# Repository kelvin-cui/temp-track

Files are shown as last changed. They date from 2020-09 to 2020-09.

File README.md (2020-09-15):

# temp-track
Temp-track is a IOT temperature sensor designed for use in the transition back to office during the pandemic. Created as a summer stretch project for Cisco, Temp-track allows for custom API integrations with its Wifi capabilities, and features the work of Tyler Patel, Tara Rafi, Olivia Xia, Michael Fitzgerald and Kelvin Cui.

covid-19

## Background info
With the advent of the Coronavirus, the entire world shifted to working from home, in an effort to limit the possibilities of infection. COVID-19 is highly contagious, and the current best way to prevent infection is through screening. An obvious symptom of COVID-19 is a fever, with a raised internal temperature. Temperature-based screening is the most common solution right now to quickly screen people before they are allowed entry, often seen at storefronts and airports. Since COVID-19 is easily transmitted through bodily fluids, the FDA recommends "telethermographic temperature sensors", or temperature sensors that can assess skin temperature remotely. 

### Existing Solutions
There are two popular solutions that currently exist for this purpose : simple IR sensor-based forehead thermometers, and advanced IR camera-based screening stations.

covid
The point-and-shoot forehead thermometers are simple to use, but they can be very inaccurate, often featuring a variance of 0.5 degrees celsius. They're also standalone units, and allows for zero integration.

covid
The camera-based screening stations meanwhile are quite advanced, featuring a variance of 0.3 degrees celsius, and allow for integrations. However, they are very expensive, are difficult to operate, and take up a lot of space.

## Proposed Solution
We believe that our solution features the best of both currently popular solutions. It features the ease of use of the forehead thermometers, while maintaining the accuracy of the IR cameras with its medical grade IR Sensor. It also features an ESP-01 Chip, allowing for custom API integrations, and best of all, costs the same on average as the forehead thermometers.

## How it works
covid

## Hardware
The hardware is based on an Arduino Nano, as well as an ESP-01 Wifi Chip. The temperature is recorded using the Medical Grade MLX90614 IR Sensor, allowing for 0.2 degrees celsius variance. When the button is pressed, the temperature is recorded, and then sent over Wifi to a server of your choice. If the temperature is below 38 degrees celsius, then a green light flashes, indicating a pass for the screening. Conversely, if the temperature is above 38, then a red light flashes. Our current example is set up to send the temperature info to our Node Red Server through a GET call, which brings us into...

## Software
In our example, our Node Red server is set up to take the temperature info, and using the Webex Teams API, send that temperature as a message to a user through Teams.

## Our Vision
Our vision is to create an all-in-one screening and contact tracing solution, utilizing two key APIs: DNASpaces and Webex Teams. With DNASpaces, we're able to anonymously track the location of any user connected to a Cisco router in a building, and determine which people have come into contact with each other. With Webex Teams, we're also able to update the building manager of any alerts, send helpful resources to anyone who's registered a high temperature, and even allow people to self-report if they've tested positive.

### Example Workflow
An example workflow for any office with Cisco routers could be the following. An employee would scan their ID badge, and get their temperatures taken. If their temperature is abnormally high, they are prevented from entering the building. The building management gets an alert that one of their employees have registered a high temperature, and that employee would be sent helpful resources, and recommended to get tested, both through Webex Teams. If the test returns positive, the employee may self-report through Teams. If they self-report, the employee's stored location data from DNASpaces is automatically compared, and any other employee who they've come into contact with will get a notification through Teams, alerting them that someone they've come into contact with has tested positive.

## Lessons Learned
This was a very educational project, and there are a few things that we'd do differently in the future. In terms of hardware, instead of using an Arduino Nano and ESP-01, an ESP-32 is a single board that accomplishes the same thing, with less cost. Using the ESP-32 would also allow us to power the device using a Li-Po, making the device standalone instead of having to be powered over USB. The ESP-32 also has a deep-sleep mode, so that it would only draw power when the button is clicked, allowing long battery life. Furthermore, some ESP-32s feature a built-in OLED screen, which would allow for a display of the actual temperature. In terms of the server, instead of sending API calls directly to Node Red, we'd set up a MQTT server that would act as a bridge between the two to allow for more efficient communications.

## File Guide
The CAD files for the housing are featured in the CAD folder. Both a .stl and .sldprt version exists, either for direct 3D printing or modification through solidworks respectively.
The Arduino and ESP Files are found in the Code folder, and a wiring Schematic.png is present to show how everything is wired together.

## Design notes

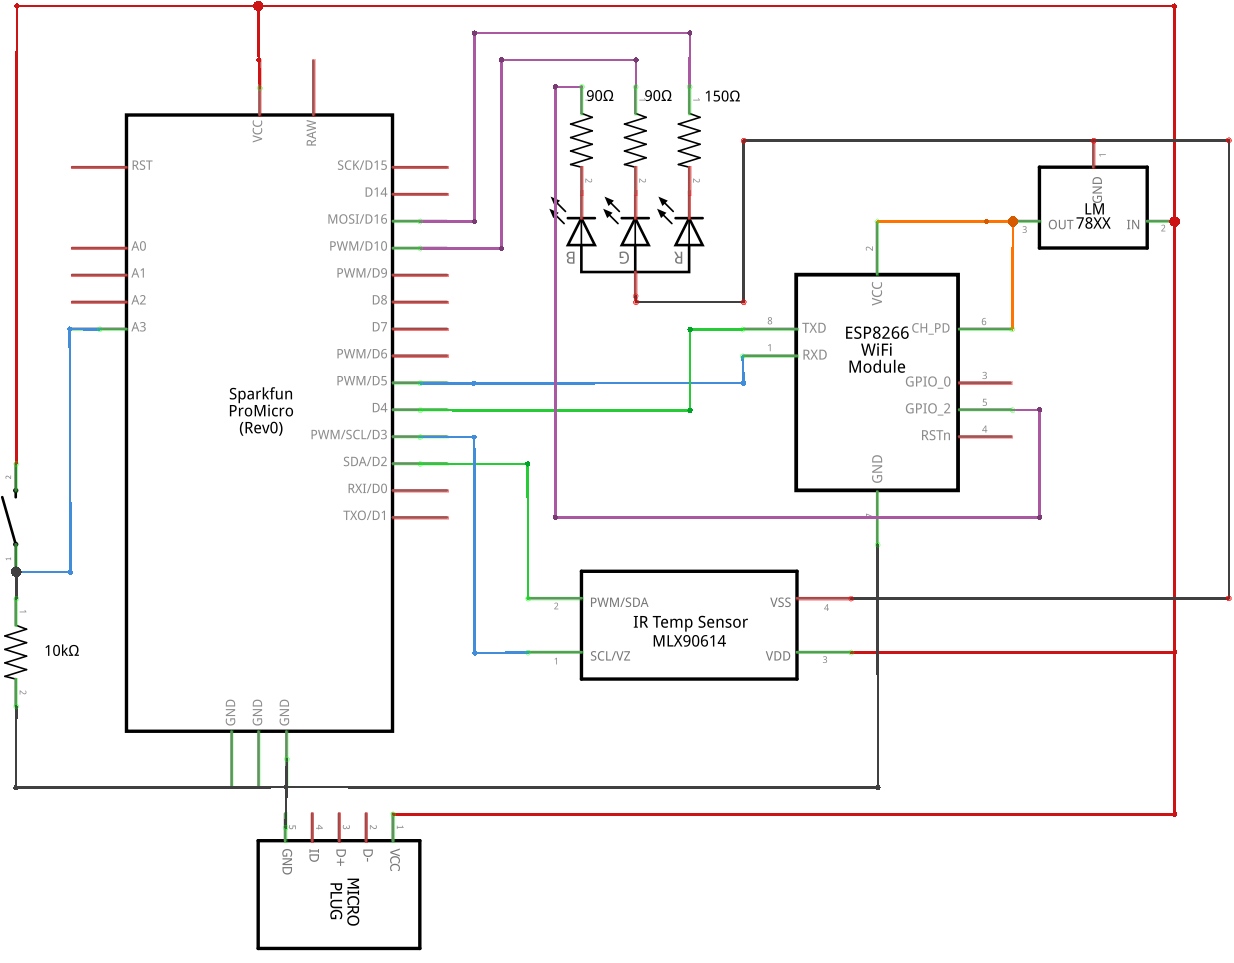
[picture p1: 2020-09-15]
Schematic.png

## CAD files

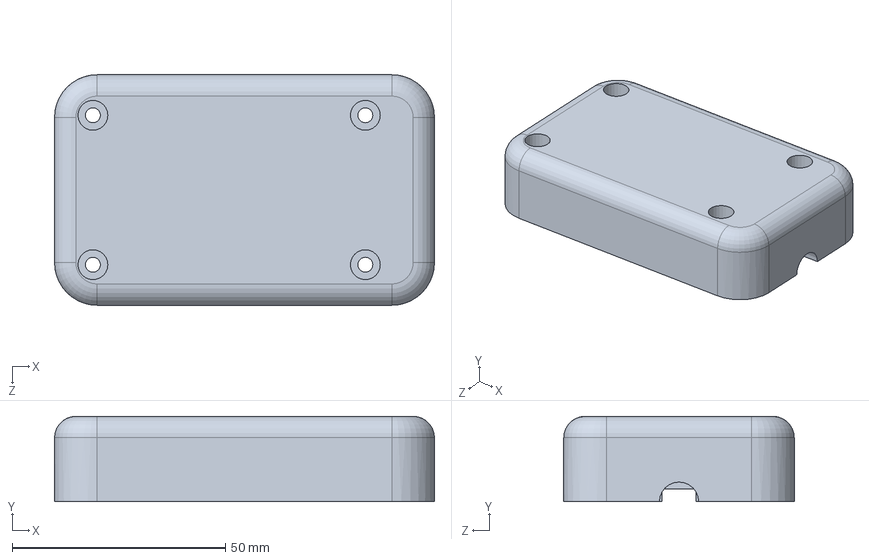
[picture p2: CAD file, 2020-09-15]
CAD/Bottom Chassis.sldprt
89.0 x 20.0 x 54.0 mm

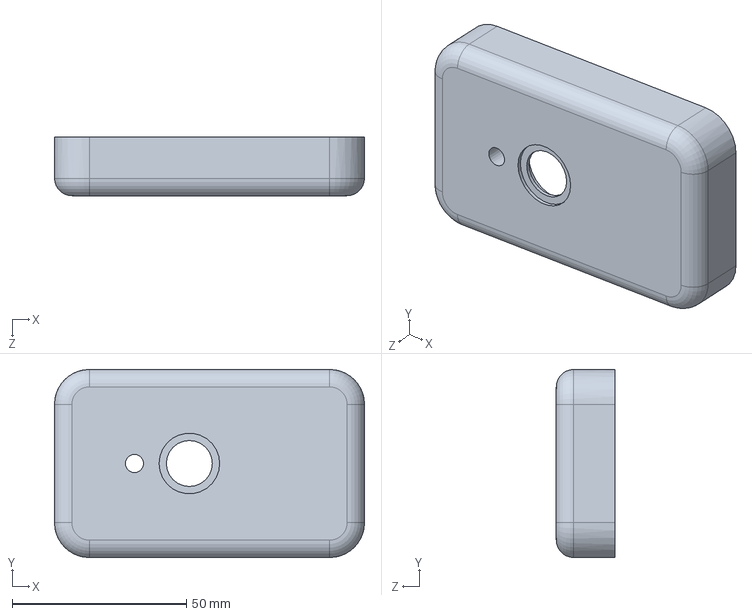
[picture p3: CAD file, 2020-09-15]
CAD/Top Chassis.SLDPRT
89.0 x 54.0 x 16.8 mm

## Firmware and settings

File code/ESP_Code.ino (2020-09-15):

#include <ESP8266WiFi.h>            //-------------------------Define use of ESP8266 Wifi Library for Wifi Setup               
#include <ESP8266WebServer.h>
#include <stdlib.h>                 //-------------------------Define use of stdlib to convert char arrays to float type


const byte numChars = 32;           //-------------------------Allocate Char array for recieved data from arduino
char receivedChars[numChars];

boolean newData = false;            //-------------------------Boolean to mark when new data is recieved

float temp;                         //-------------------------Float to store temp from Arduino

int bled = 2;                       //-------------------------Initalize blue LED on Pin 2(GPIO2) and onboard LED on pin 1(onboard)
int led = 1;


//-----------------------BASIC WIFI SETTINGS-------------------------//
const char* ssid = "SSID"; //Change to reflect local network
const char* password = "YOURPASS";   //Ditto

const char* host = "api.thingspeak.com"; //Domain to Server
const char* path = "/update?api_key=PO0IANZGAXMFCJMV&field1="; //Path of Server
int refreshtime = 15; //Make new HTTPS request after x seconds

void setup() {                    //------------------------------Setup, run once when powered on
  Serial.begin(115200);                  //--------------------------For Commmunication with Arduino 
  pinMode(bled, OUTPUT);                 //--------------------------Set LED pins as outputs
  pinMode(led, OUTPUT);

  WiFi.mode(WIFI_STA);                   //--------------------------Set ESP to Station mode, instead of Access Point
  WiFi.begin(ssid, password);            //--------------------------Connect to the Wifi network as defined in BASIC WIFI SETTINGS
  
  
  while (WiFi.status() != WL_CONNECTED) {//--------------------------Waiting for Wifi Connection
    digitalWrite(bled, HIGH);            //--------------------------Flash the Blue LED to indicate connecting...
    delay(500);
    Serial.print("Connecting..");
    digitalWrite(bled, LOW);
    delay(500);
  }
}

void loop() {                     //------------------------------Loop, keep running while on
  if (WiFi.status() == WL_CONNECTED) { //----------------------------While Wifi is connected
    recvTemp();                        //----------------------------Function to recieve temp from arduino
    sendTemp();                        //----------------------------Function to send temp to the server
  }
}

void recvTemp() {                 //------------------------------Function for recieving temperature float over serial
    static byte ndx = 0;               //------------------------------Set char index to zero 
    char endMarker = '\n';             //------------------------------Set "end marker" to newline symbol 
    char rc;                           //------------------------------Allocate rc char for recieved char
   
    if (Serial.available() > 0) {      //------------------------------If Serial is connected
        rc = Serial.read();            //------------------------------Read the character sent, and save to rc

        if (rc != endMarker) {         //------------------------------If the recieved character isn't a newline 
            receivedChars[ndx] = rc;   //------------------------------Add the recieved character to our character array
            ndx++;                     //------------------------------Increase char index by one
            if (ndx >= numChars) {     //------------------------------Code to ensure that recieved data isn't longer than the character array we defined - not an issue in our use case can ignore
                ndx = numChars - 1;    
            }
        }
        else {                          //------------------------------If the recieved character is a newline, marking the end of a transmission
            receivedChars[ndx] = '\0';  //------------------------------End the char array with \0 that tells arduino that the char array ends
            ndx = 0;                    //------------------------------Set char index back to zero
            newData = true;             //------------------------------Set the newData boolean to true, letting the sendTemp function know that this data hasn't been sent before
        }
    }
}

void sendTemp() {                 //---------------------------------Function for sending temps to server
    if (newData == true) {           //----------------------------------If this data hasn't already been sent

        temp = 0.0;                  //----------------------------------Reset the temp float 
        temp = atof(receivedChars);  //----------------------------------Convert the recieved data to a float type from char array, store in "temp"
        updatetemp(temp);            //----------------------------------Run updatetemp helper function
        newData = false;             //----------------------------------Mark Data as sent, so sendTemp doesn't send it again
        
    }
}


void updatetemp(float temp){       //---------------------------------Helper function for sending data to server
  WiFiClient httpsClient;             //---------------------------------Start Wifi Client
  httpsClient.setTimeout(15000);      //---------------------------------Set Timeout to 15seconds
  delay(1000);
  int retry = 0;                      //---------------------------------Set retry counter to zero
  while ((!httpsClient.connect(host, 80)) && (retry < 15)) { //----------While the client hasn't connected to the host, and there has been less than 15 retries
    delay(1000);                                             //----------Wait one second then try again
    retry++;                                                 //----------Increase the retry counter
  }
  if (retry == 15) {                                         //----------If 15 retries are attempted and still no connection
    Serial.println("Connection failed");                     
    digitalWrite(led, HIGH);                                 //----------Flash onboard LED signifying no connection made
    delay(500);
    digitalWrite(led, LOW);
    delay(500);
    digitalWrite(led, HIGH);
    delay(500);
    digitalWrite(led, LOW);
  }
  else {                                                      //---------If Conenction Successful
    Serial.println("Connected to Server");
    digitalWrite(bled, HIGH);                                 //---------Turn on Blue LED, signaling start of data transmission
  }
  httpsClient.print(String("GET ") + path + String(temp) +    //---------Send a GET request, with temp in the url
                    " HTTP/1.1\r\n" +
                    "Host: " + host +
                    "\r\n" + "Connection: close\r\n\r\n");
  while (httpsClient.connected()) {                           //----------Recieve Data sent from Server (not used in our case, server doesn't send any data)
    
    String line = httpsClient.readStringUntil('\n');
    if (line == "\r") {
      break;
    }
  }
  
  delay(1000);                                                //-----------Wait one second, before closing the client
  httpsClient.stop();
  digitalWrite(bled, LOW);                                    //-----------Turn off the Blue LED, signifying end of data transmission
}

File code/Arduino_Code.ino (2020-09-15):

#include <Wire.h>           //-------------------------Define use of MLX90614 Temperature sensor library
#include <Adafruit_MLX90614.h>

#include <SoftwareSerial.h> //-------------------------Define use of Software Serial, setting RX to pin 4 and TX to pin 5
#define RXpin 4
#define TXpin 5
SoftwareSerial espSerial(RXpin, TXpin);


Adafruit_MLX90614 mlx = Adafruit_MLX90614(); //-------Initalize name of Tempsensor, and float to store temperature once taken
float temp = 0;


const int button = 21; //-----------------------------Initalize Button on Pin 21 (A3), as well as button state and reset variables  
int buttonState = 0;
int buttonReset = 0;


const int rled = 16;  //------------------------------Initalize Red LED on Pin 16, and Green LED on Pin 10.
const int gled = 10;

void setup() {        //------------------------------Setup, run once when powered on
  
  //Serial.begin(9600);    //-------------------------For communication with computer
  espSerial.begin(115200); //-------------------------For communication with ESP Wifi Module
  
  mlx.begin();             //--------------------------Start temperature sensor 

  pinMode(button, INPUT);  //--------------------------Set Button as an input

  pinMode(rled, OUTPUT);   //--------------------------Set LEDs as outputs
  pinMode(gled, OUTPUT);
  
}

void loop() {         //------------------------------Loop, keep running while on
  gettemp(); //--------------------------------------Loop gettemp function
}


void gettemp() {//-----------------------------------Main function, when button is pressed, gets temperature and stores into float temp, sets LED based on temp values, and sends to ESP Chip
  
  buttonState = digitalRead(button);             //------------------------------Read Button State (HIGH = Pressed Down, LOW = Not Pressed)

  if (buttonState == HIGH && buttonReset == 0){    //-----------------------------If the button is pressed, and the previous state was not pressed (reset == 0)
    temp = mlx.readObjectTempC();                   //---------------------------Get the temperature in C, and store to float "temp"
    //temp = mlx.readObjectTempF();                 //---------------------------Use this line for temperature in F
    
    setLED(temp);                                   //---------------------------Use the setLED helper function to change LED color based on temp
    
    //Serial.print("*C\tObject = ");                //---------------------------Use for Debugging the temperature read by sensor - Must uncomment Serial.begin in Setup for this to work
    //Serial.print(temp); 
    //Serial.println("*C");
    
    espSend(temp);                                  //---------------------------Use the espSend helper function to send the temp float to the ESP Chip
    
    buttonReset = 1;                                //---------------------------Set the previous state to pressed (reset = 1)
  } 
  
  else if (buttonState == LOW && buttonReset == 1){//----------------------------If the button isn't pressed, and the previous state was pressed (reset == 1)
    buttonReset = 0;                                //---------------------------Set previous state to not pressed (reset = 0)
  }
  delay(100);                                     //-----------------------------Pause for 100 Milliseconds
}

void setLED(float temp) { //-------------------------Helper Function, given a temperature, set LEDs to different colors
  if (temp > 35) {             //------------------------------------------------When the temperature is higher than 35 (35 used for demo, COVID tests for 38 and above, Temperature sensor has error of +-0.5 so setting to 38.5 and above is safe)
     digitalWrite(rled, HIGH); //------------------------------------------------Turn on the red LED
     delay(500);               //------------------------------------------------Pause for half a second (500 milliseconds)
     digitalWrite(rled, LOW);  //------------------------------------------------Turn the red LED off again
  }
  else {
    digitalWrite(gled, HIGH); //-------------------------------------------------When the temperature is lower or equal to 35
    delay(500);               //-------------------------------------------------Pause for half a second
    digitalWrite(gled, LOW);  //-------------------------------------------------Turn the green LED off again
  }
  
}

void espSend(float data) { //------------------------Helper Function, given a float, send to ESP
  espSerial.println(data, 3); //-------------------------------------------------Send float via Software Serial to ESP

}
